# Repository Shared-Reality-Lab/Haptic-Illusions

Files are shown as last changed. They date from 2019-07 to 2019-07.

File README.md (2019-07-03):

# 3D Printed Haptic Illusions and Demonstrations
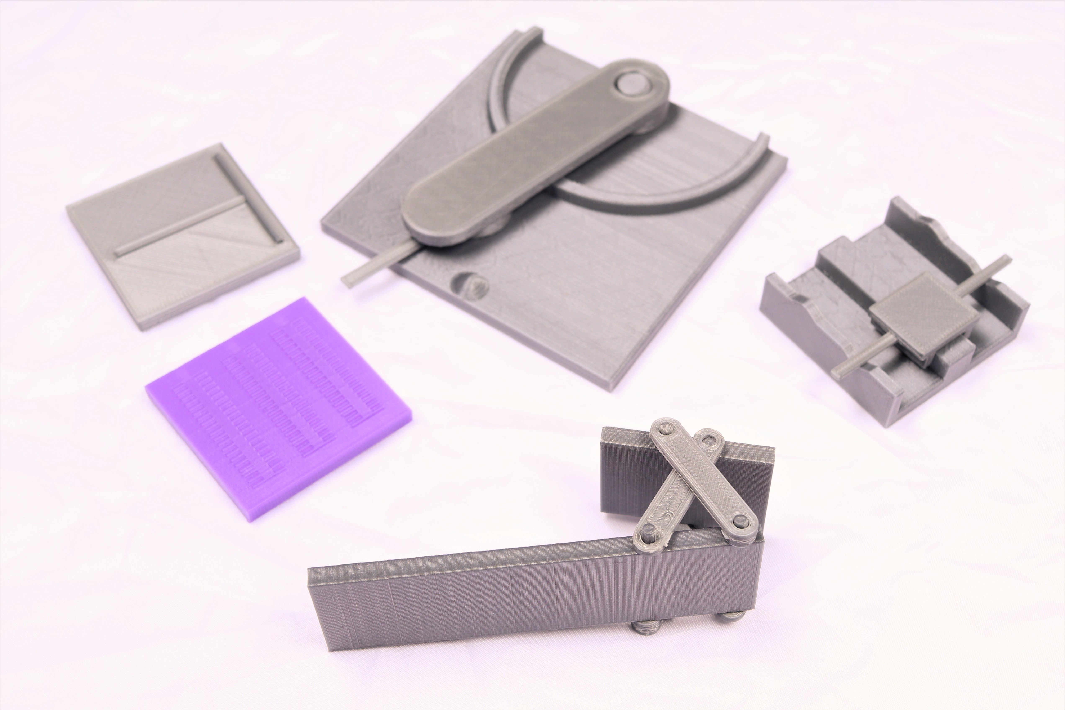
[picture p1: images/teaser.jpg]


Appreciating a sensory illusion often requires you to experience it with your own senses. While this is generally trivial for visual and auditory illusions that can be rendered using commonly available hardware, haptic illusions often require complex mechanical systems.
Vincent Hayward’s, “A brief taxonomy of tactile illusions and demonstrations that can be done in a hardware store” introduced simple and affordable DIY assemblies to make haptic illusions more accessible.
However, we argue that the skills and materials required to fabricate the illusions he describes are often non-trivial, thereby depriving the paper’s intended audience from experiencing and learning about these haptic illusions.
As a novel, more accessible alternative, we propose a series of haptic illusions and demonstrations that can be fabricated using any FDM 3D printer.
Once printed, they can be fully assembled by hand.

In this repository you will find all necessary 3D model files (.stl) and printing guidelines to fabricate your own set of 3D printed illusions and demonstrations.

Antoine Weill-Duflos, Pascal E. Fortin, Jeremy R. Cooperstock<br/>
Shared Reality Lab, McGill University

# 3D printing guidelines

The table below specifics the files necessary to fabricate each illusion, provides a few guidelines on how to print each activity and shows an example of model layout on the 3D printer's print surface.

|Illusion|Files|Printing guidelines|Example FDM printing orientation|
|---|---|---|---|
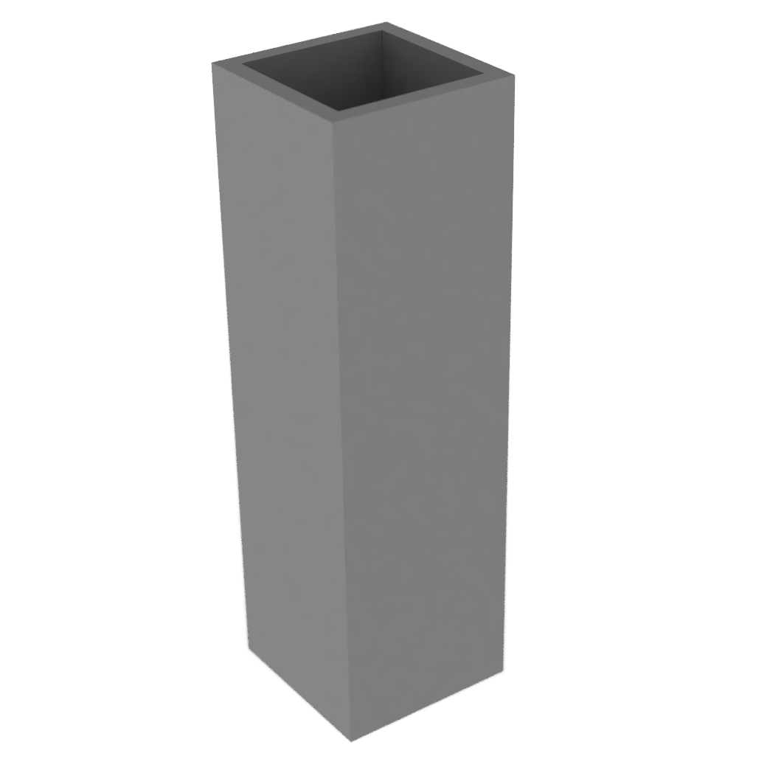
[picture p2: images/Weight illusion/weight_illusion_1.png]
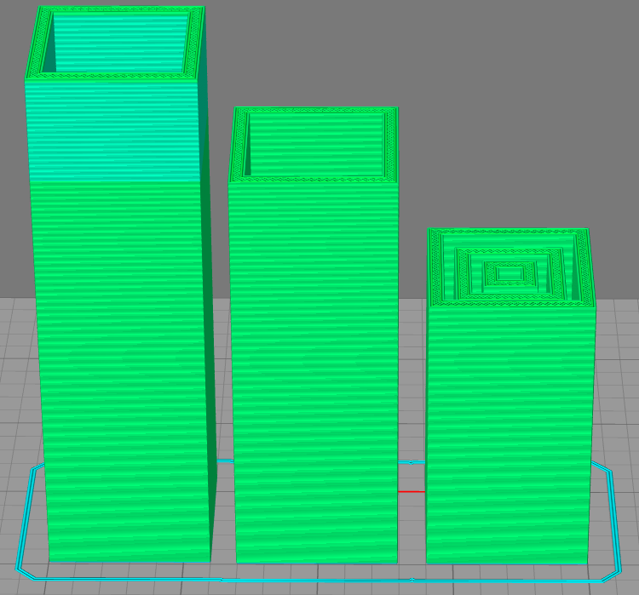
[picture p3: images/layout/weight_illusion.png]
|<br/>Classic Weight Illusion|1 x sizeillubig.stl<br/>1 x sizeillumedium.stl<br/>1 x sizeillusmall.stl|Make sure you print each file with the exact same slicer settings to ensure that they have approximately the same mass (e.g., layer height, infill %, number of walls, number of top/bottom layers).||
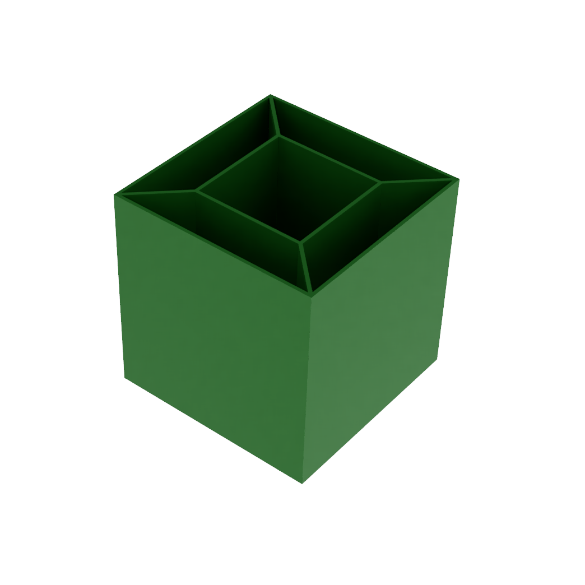
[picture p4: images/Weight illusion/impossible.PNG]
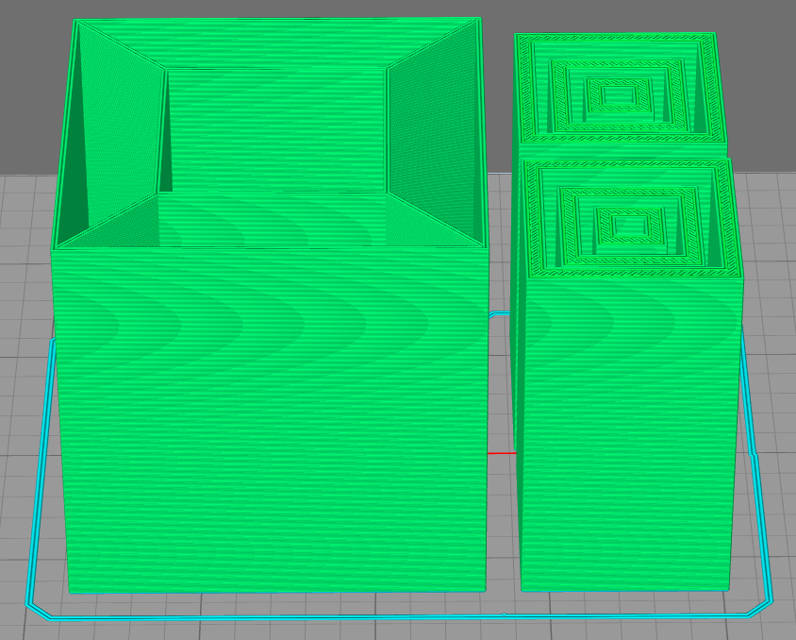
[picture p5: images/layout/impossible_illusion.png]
|<br/>Impossible Weight Illusion|1 x impossiblebox.stl<br/>2 x impossibleinside.stl|Make sure you print each file with the exact same slicer settings to ensure that they have approximately the same mass (e.g., layer height, infill %, number of walls, number of top/bottom layers).||
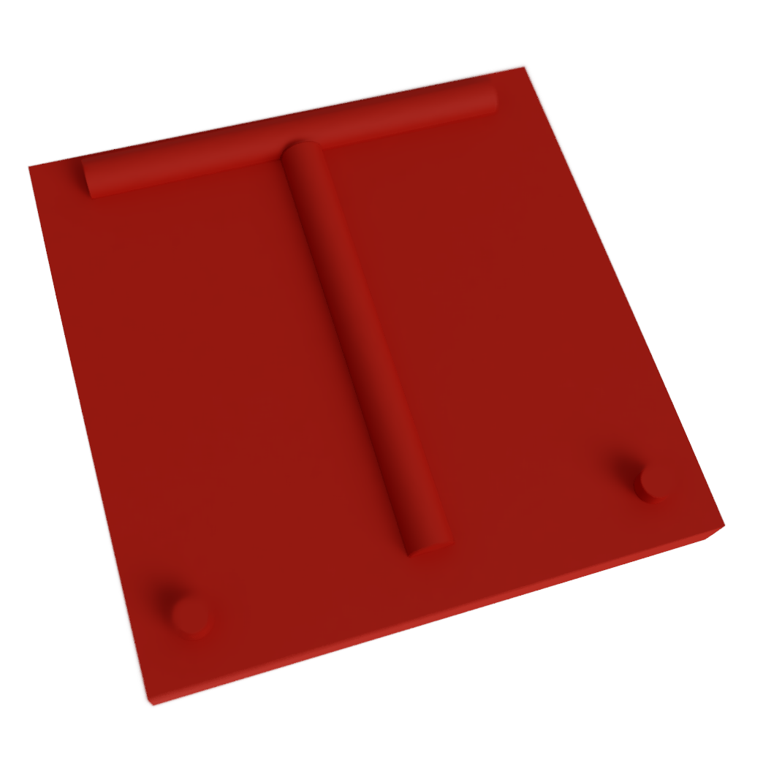
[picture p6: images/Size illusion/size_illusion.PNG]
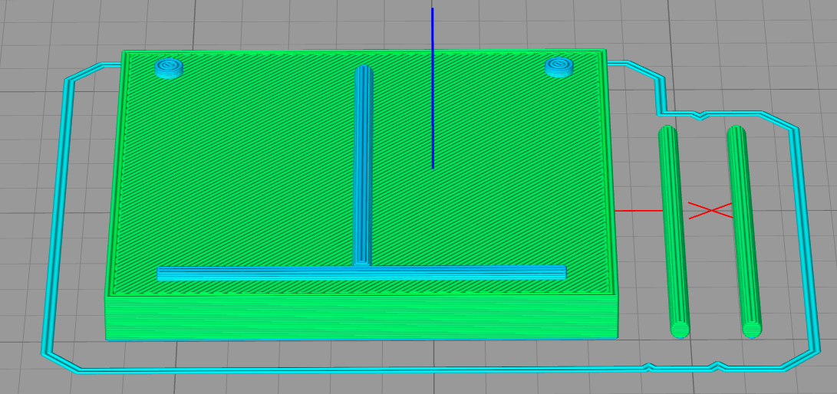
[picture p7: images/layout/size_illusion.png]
|<br/>Size Illusion|1 x plate.stl<br/>2 x stick.stl|You may have to print stick.stl files on their side if you are having difficulties getting them to stick on the printing surface.||
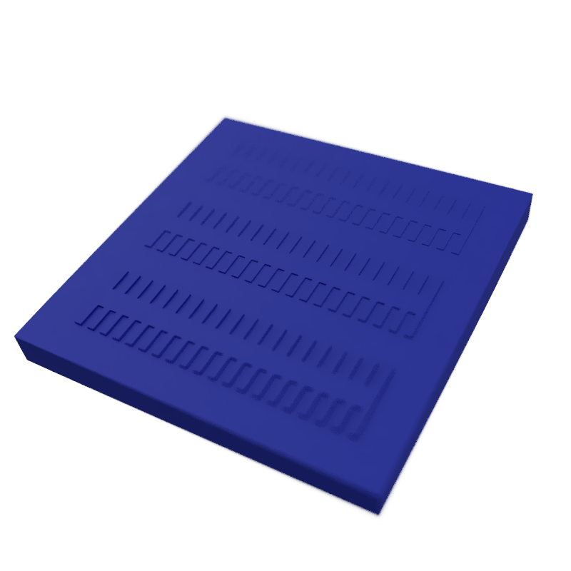
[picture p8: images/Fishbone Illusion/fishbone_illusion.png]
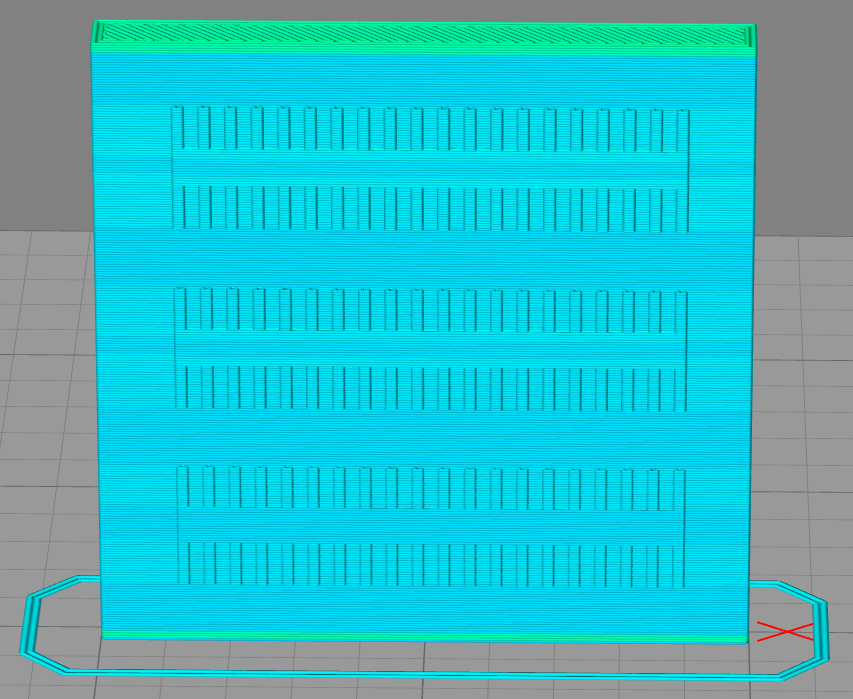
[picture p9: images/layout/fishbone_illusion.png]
|<br/>Fishbone Illusion|1 x fishbone.stl|If using a FDM 3D printer, this file should be printed on its side, such that the layers are parallel with the finger travel. The intent is to minimize friction between the finger and the layer lines. Supports should be avoided, but may be needed depending on your 3D printer's performance.||
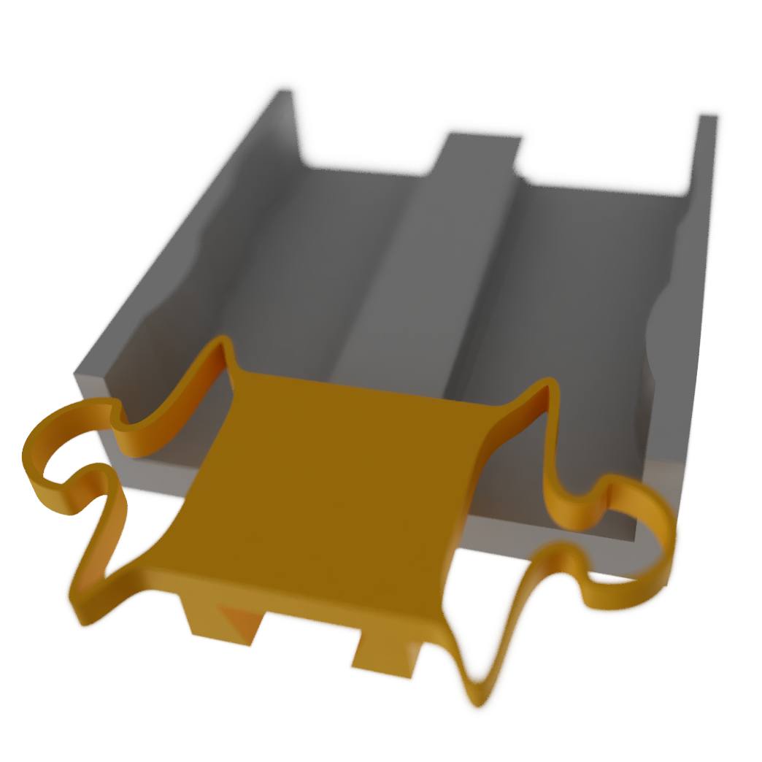
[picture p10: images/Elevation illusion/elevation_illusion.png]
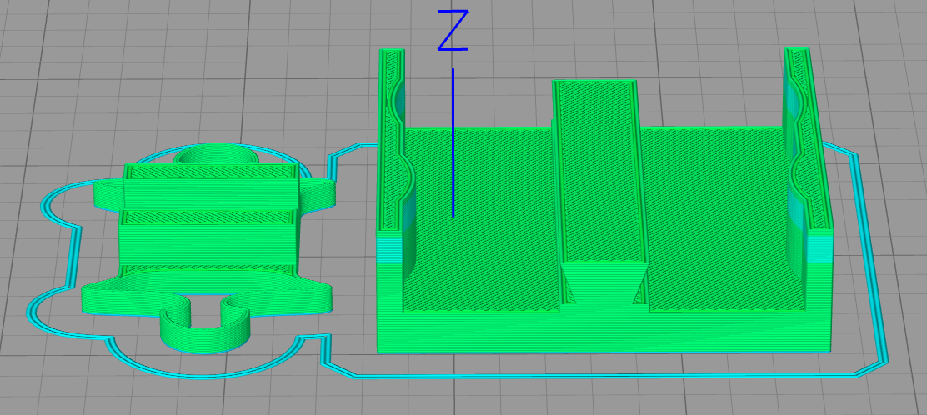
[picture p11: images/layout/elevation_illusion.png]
|<br/>Elevation Illusion|1 x elev-base.stl<br/>1 x elev-mobile.stl| The base should be printed flat, such that layers are parallel to the "ground" to reduce friction during motion. The mobile component should be printed on its back to avoid the need for supports and have layers aligned with the base.||
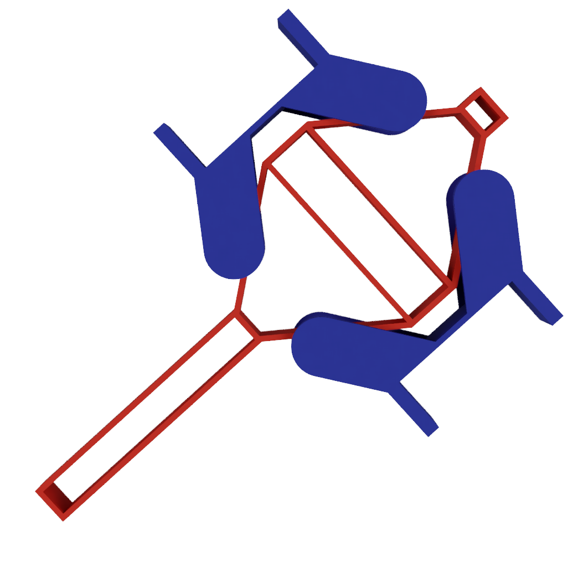
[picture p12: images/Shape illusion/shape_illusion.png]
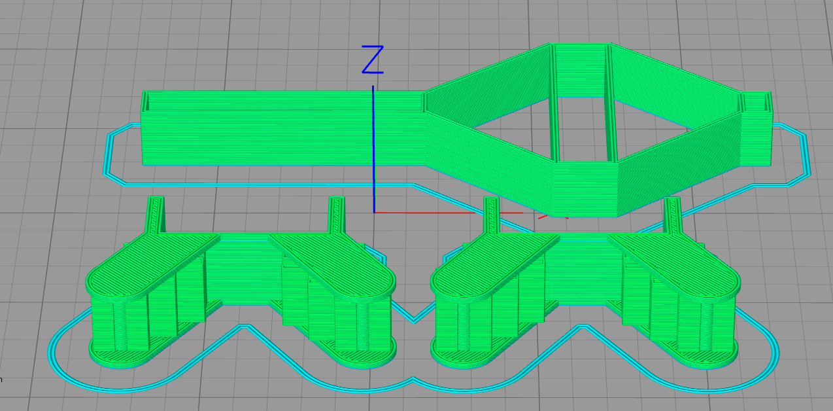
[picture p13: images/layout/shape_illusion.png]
|<br/>Elevation Illusion|1 x came.stl<br/>2 x galet.stl|Came.stl should be printed on its side and should not require any support structures. galet.stl should be printed on its side and should be printed with supports.||

# Credit
This work is heavily inspired by "A brief taxonomy of tactile illusions and demonstrations that can be done in a hardware store" by Vincent Hayward. We believe that our efforts are aligned with Hayward's original intent, which was to make tactile illusions and demonstrations more accessible to the general public.

Hayward, V. (2008). A brief taxonomy of tactile illusions and demonstrations that can be done in a hardware store. Brain Research Bulletin, 75(6), 742–752. https://doi.org/10.1016/J.BRAINRESBULL.2008.01.008

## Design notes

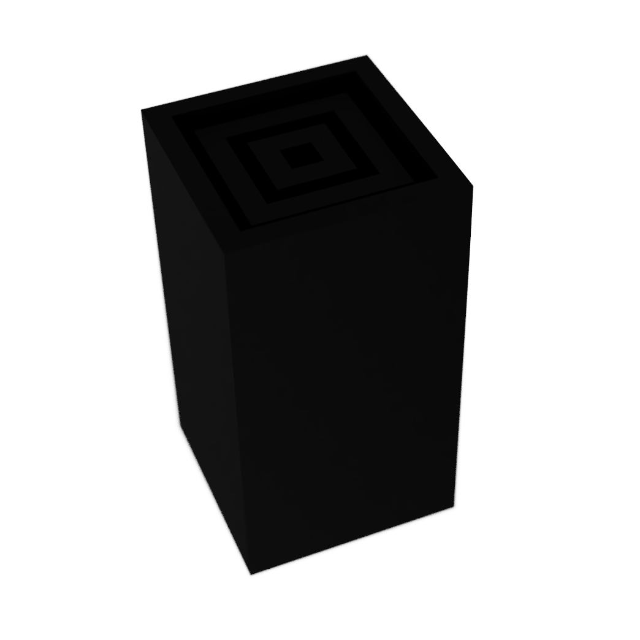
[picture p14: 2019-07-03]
images/Weight illusion/weight_illusion_2.png

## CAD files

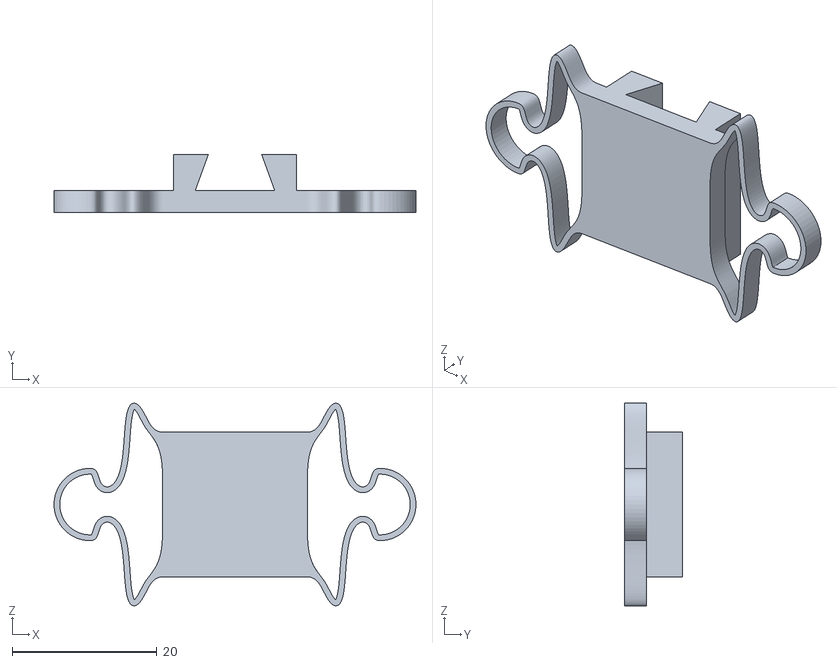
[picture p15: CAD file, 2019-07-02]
Elevation illusion/elev-mobile.stl
50.0 x 8.00 x 28.0

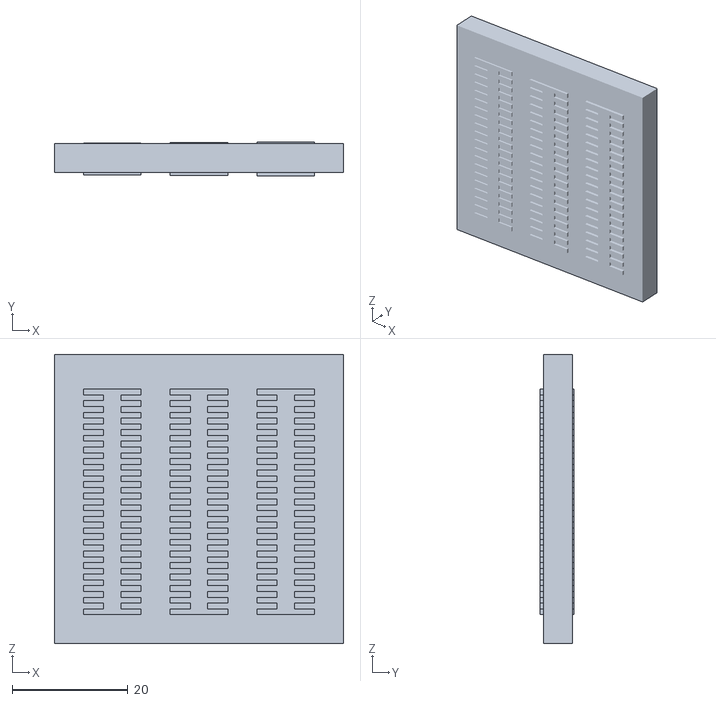
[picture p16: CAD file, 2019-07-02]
Fishbone illusion/fishbone.stl
50.0 x 5.90 x 50.0

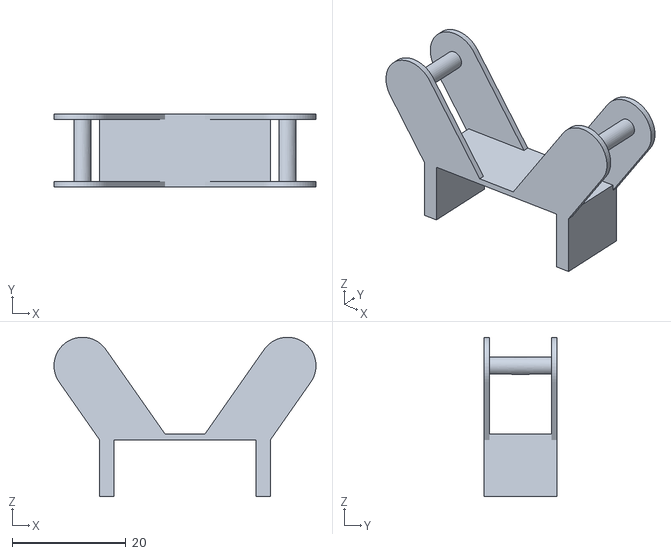
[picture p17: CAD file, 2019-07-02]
Shape illusion/galet.stl
46.0 x 12.8 x 28.0

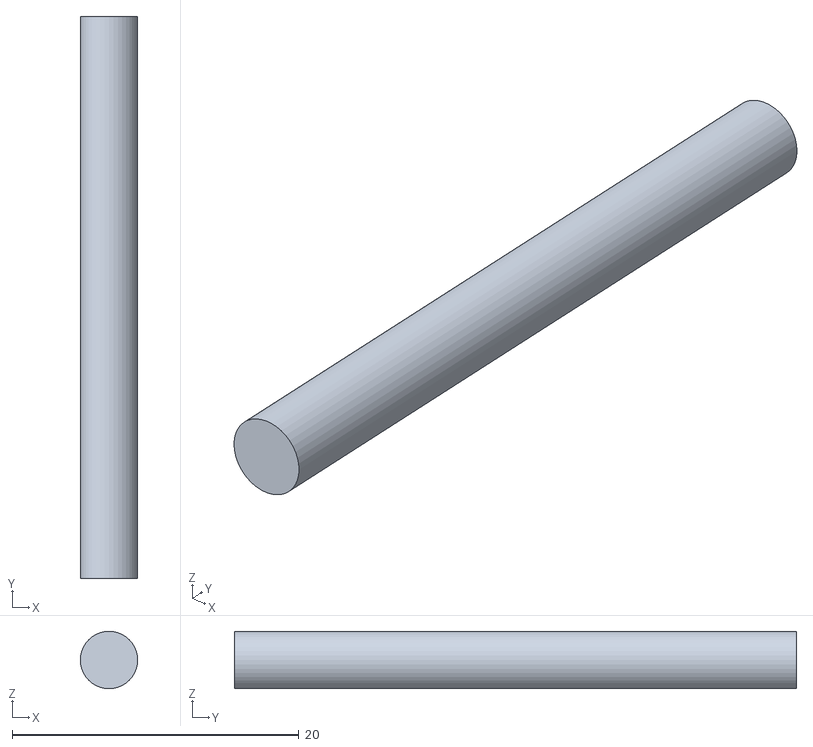
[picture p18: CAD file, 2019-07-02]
Size illusion/stick.stl
4.00 x 39.2 x 4.00

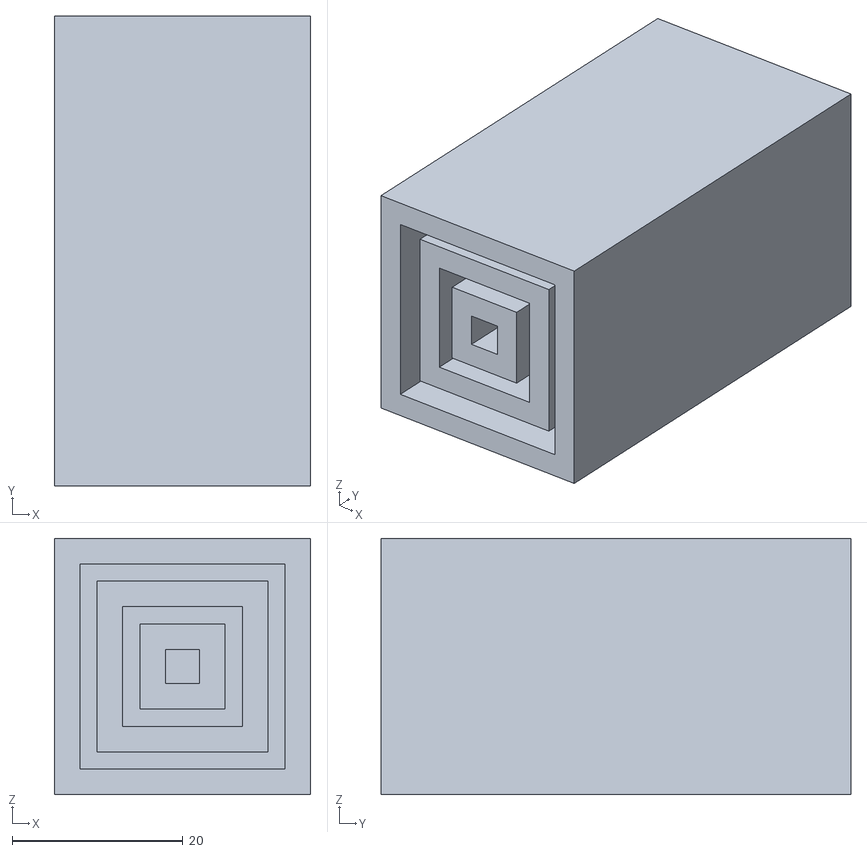
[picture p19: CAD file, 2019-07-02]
Weight illusion/Classic/sizeillusmall.stl
30.0 x 55.0 x 30.0

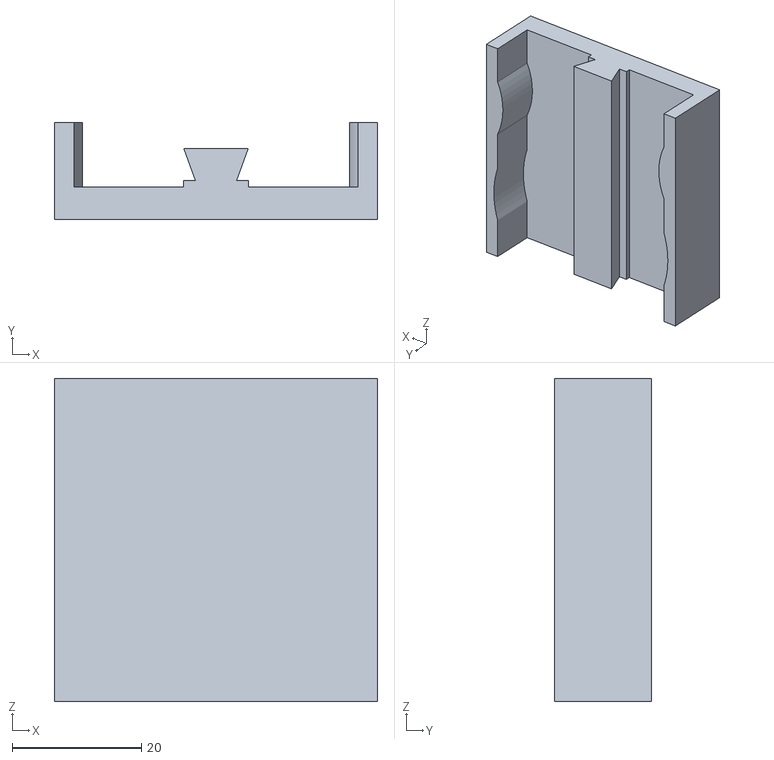
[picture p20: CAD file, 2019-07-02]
Elevation illusion/elev-base.stl
50.0 x 15.0 x 50.0

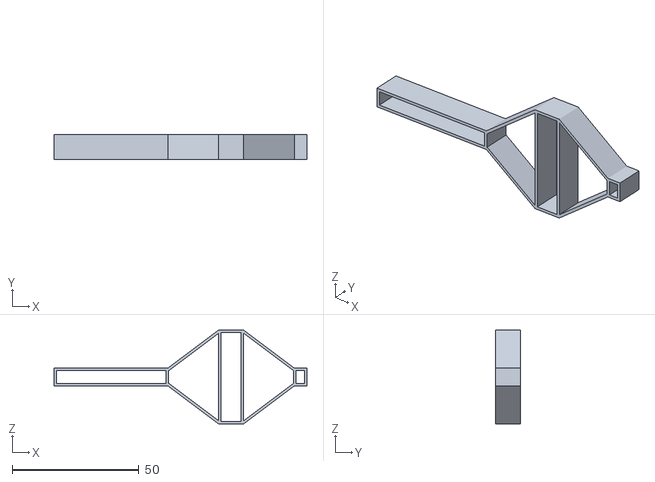
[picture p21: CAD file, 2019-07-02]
Shape illusion/came.stl
100.0 x 10.0 x 37.0

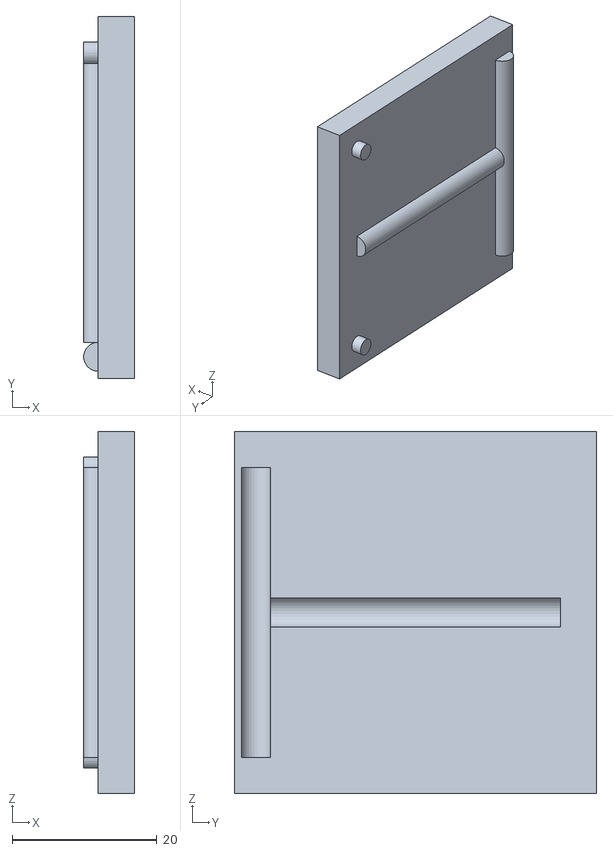
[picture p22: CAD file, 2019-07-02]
Size illusion/plate.stl
7.00 x 50.0 x 50.0

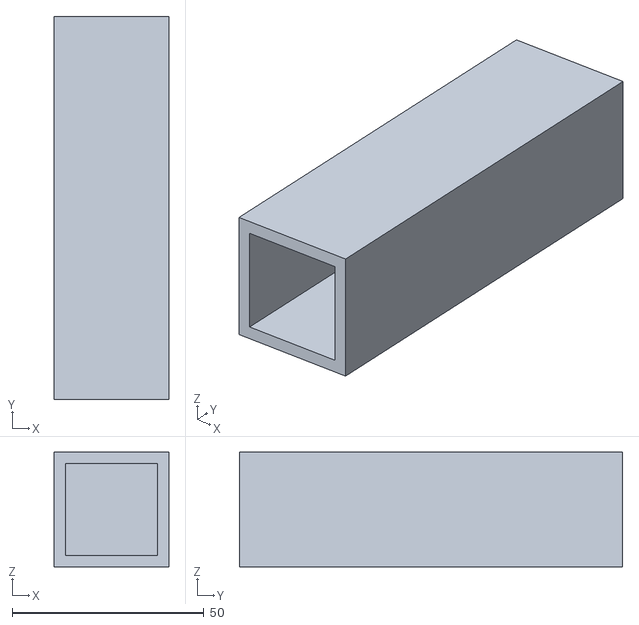
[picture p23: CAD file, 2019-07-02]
Weight illusion/Classic/sizeillubig.stl
30.0 x 100.0 x 30.0

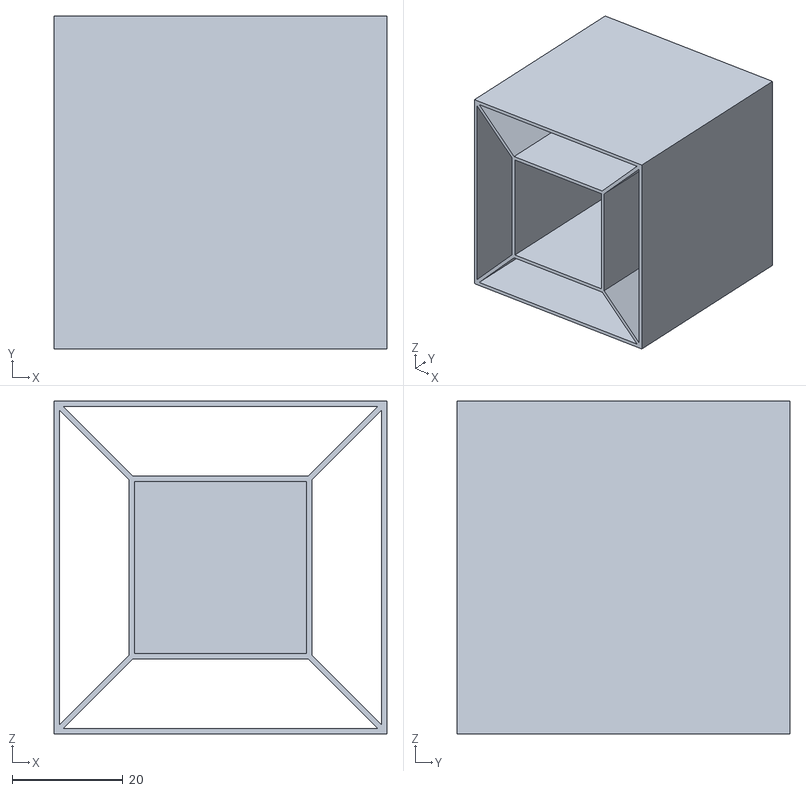
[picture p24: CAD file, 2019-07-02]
Weight illusion/Imbossible/impossiblebox.stl
60.0 x 60.0 x 60.0

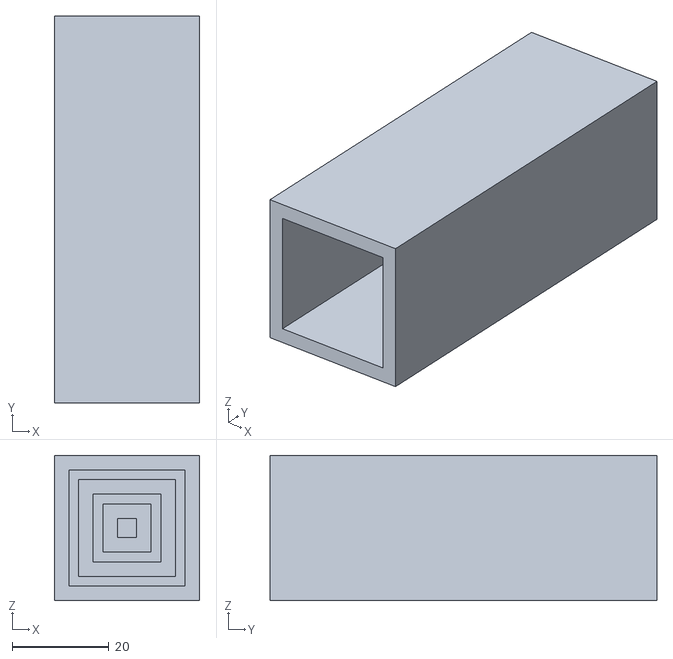
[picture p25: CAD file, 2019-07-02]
Weight illusion/Classic/sizeillumedium.stl
30.0 x 80.0 x 30.0

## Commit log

2019-07-02 Added first gen of illusions
    [came.stl, elev-base.stl, elev-mobile.stl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]
2019-07-03 Included print surface pictures
